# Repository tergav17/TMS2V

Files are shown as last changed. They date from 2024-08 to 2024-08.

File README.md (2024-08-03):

# TMS2V
This project aims to allow a V9938 VDP to be installed in place of a TMS9918A. Since the V9938 is (largely) backwards compatible with the TMS9918A, existing software for upgraded systems should still function as normal. 
Besides interposing the 40-pin socket that the TMS9918A plugged into, an extra address line may be attacked to the bus to allow for addressing of the addition 2 ports found on the V9938.

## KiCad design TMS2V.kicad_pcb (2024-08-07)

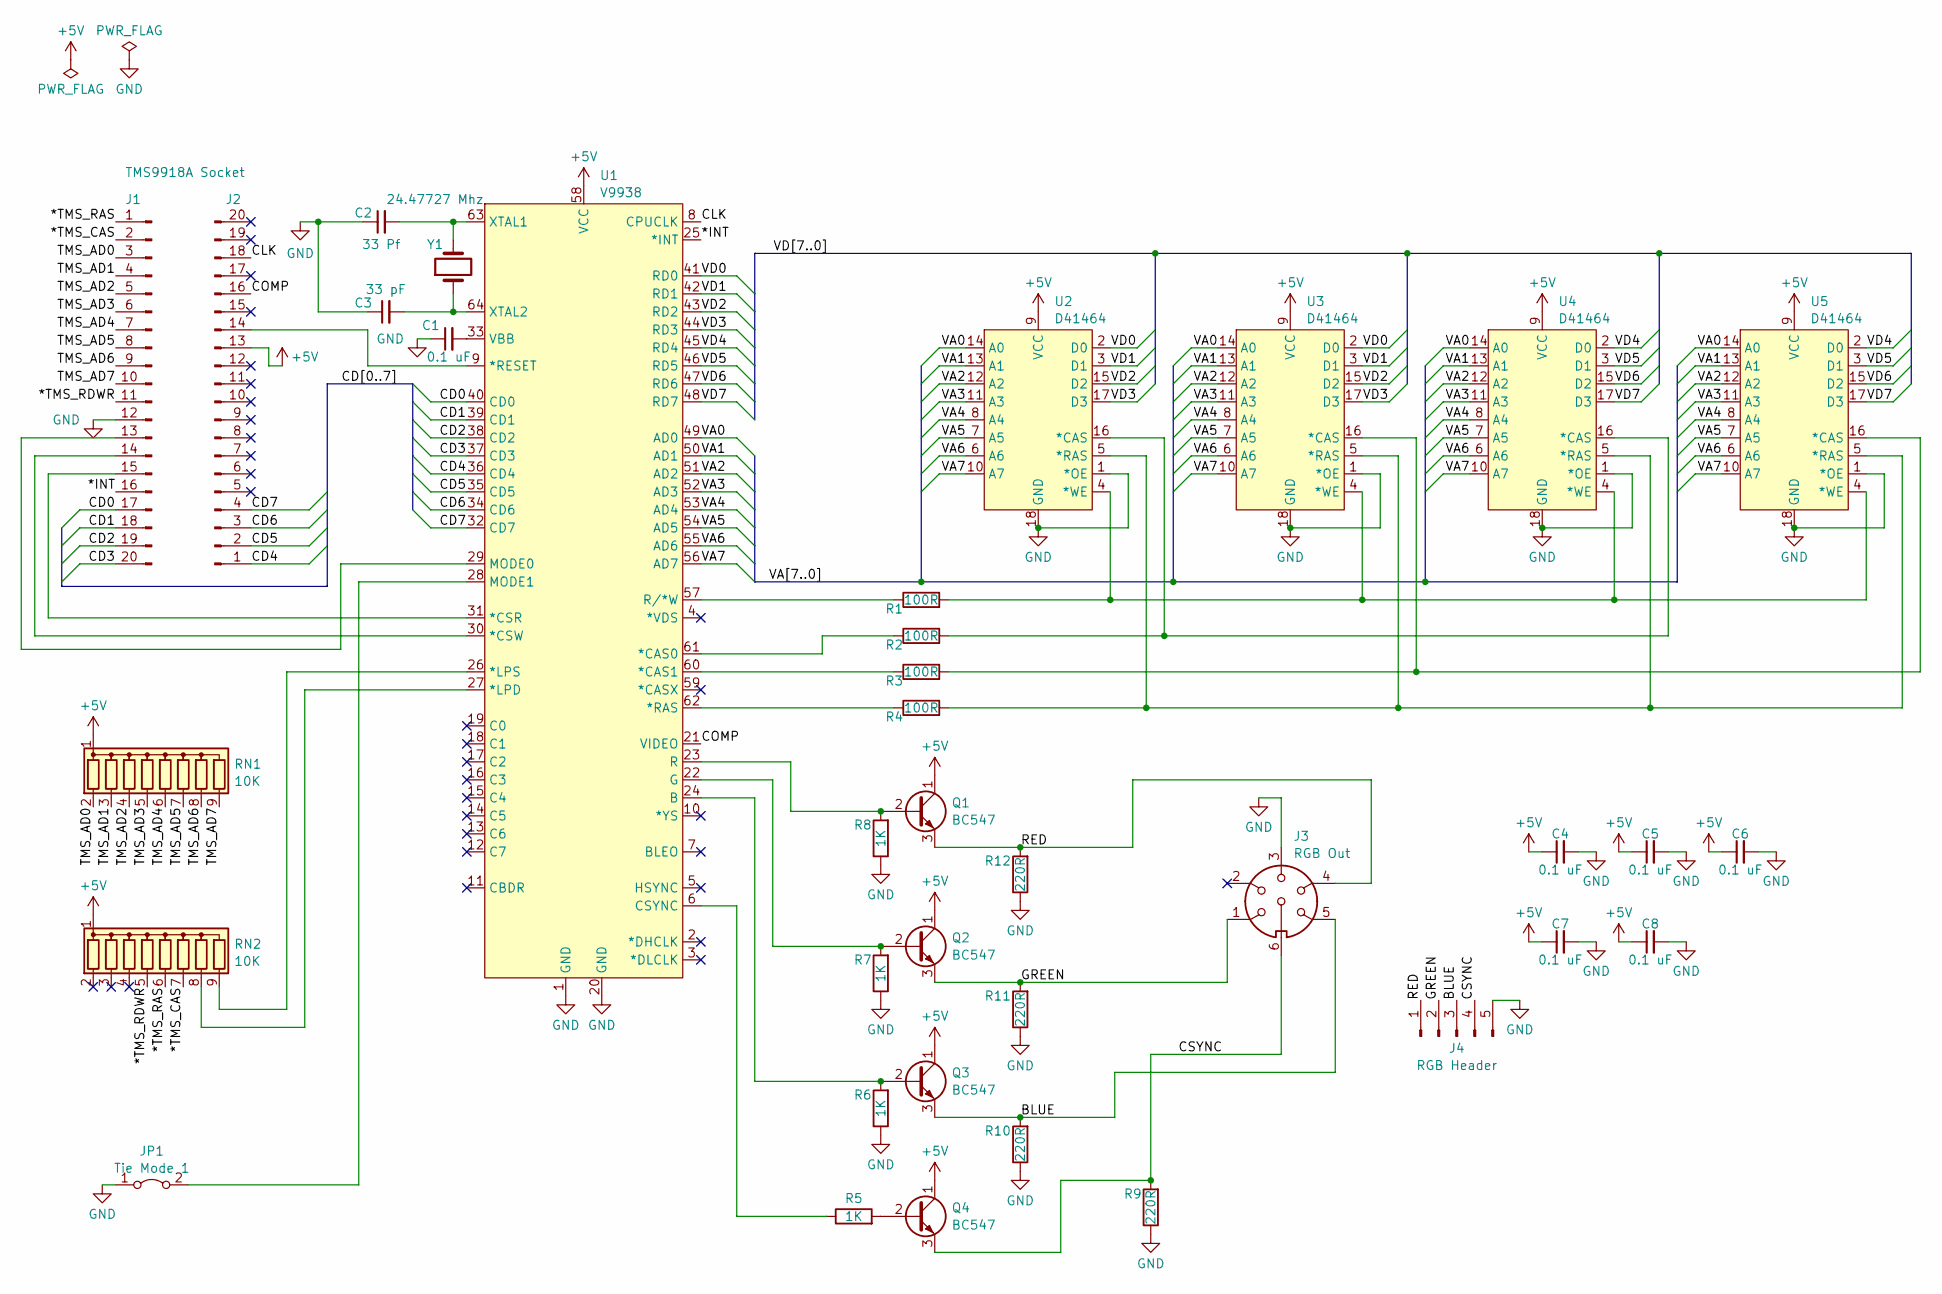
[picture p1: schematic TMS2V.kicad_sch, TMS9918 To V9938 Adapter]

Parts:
C1, C4, C5, C6, C7, C8: 0.1 uF; C_Disc_D5.0mm_W2.5mm_P5.00mm
C2: 33 Pf; C_Disc_D5.0mm_W2.5mm_P5.00mm
C3: 33 pF; C_Disc_D5.0mm_W2.5mm_P5.00mm
J1: TMS9918A Socket; PinHeader_1x20_P2.54mm_Vertical
J2: PinHeader_1x20_P2.54mm_Vertical
J3: RGB Out; DIN-6
J4: RGB Header; PinHeader_1x05_P2.54mm_Vertical
JP1: Tie Mode 1; PinHeader_1x02_P2.54mm_Vertical
Q1, Q2, Q3, Q4: BC547; TO-92_Inline
R1, R2, R3, R4: 100R; R_Axial_DIN0207_L6.3mm_D2.5mm_P7.62mm_Horizontal
R5, R6, R7, R8: 1K; R_Axial_DIN0207_L6.3mm_D2.5mm_P7.62mm_Horizontal
R9, R10, R11, R12: 220R; R_Axial_DIN0207_L6.3mm_D2.5mm_P7.62mm_Horizontal
RN1, RN2: 10K; R_Array_SIP9
U1: V9938; DIP64
U2, U3, U4, U5: D41464; DIP-18_W7.62mm
Y1: 24.47727 Mhz; Crystal_HC49-U_Vertical

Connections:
+5V: C4.1, C5.1, C6.1, C7.1, C8.1, J2.13, Q1.1 (C), Q2.1 (C), Q3.1 (C), Q4.1 (C), RN1.1 (common), RN2.1 (common), U1.58 (VCC), U2.9 (VCC), U3.9 (VCC), U4.9 (VCC), U5.9 (VCC)
/*INT: J1.16, U1.25 (*INT)
/*TMS_CAS: J1.2, RN2.7 (R6)
/*TMS_RAS: J1.1, RN2.6 (R5)
/*TMS_RDWR: J1.11, RN2.5 (R4)
/BLUE: J3.5, J4.3, Q3.3 (E), R10.2
/CD0: J1.17, U1.40 (CD0)
/CD1: J1.18, U1.39 (CD1)
/CD2: J1.19, U1.38 (CD2)
/CD3: J1.20, U1.37 (CD3)
/CD4: J2.1, U1.36 (CD4)
/CD5: J2.2, U1.35 (CD5)
/CD6: J2.3, U1.34 (CD6)
/CD7: J2.4, U1.32 (CD7)
/CLK: J2.18, U1.8 (CPUCLK)
/COMP: J2.16, U1.21 (VIDEO)
/CSYNC: J3.6, J4.4, Q4.3 (E), R9.2
/GREEN: J3.1, J4.2, Q2.3 (E), R11.2
/RED: J3.4, J4.1, Q1.3 (E), R12.2
/TMS_AD0: J1.3, RN1.2 (R1)
/TMS_AD1: J1.4, RN1.3 (R2)
/TMS_AD2: J1.5, RN1.4 (R3)
/TMS_AD3: J1.6, RN1.5 (R4)
/TMS_AD4: J1.7, RN1.6 (R5)
/TMS_AD5: J1.8, RN1.7 (R6)
/TMS_AD6: J1.9, RN1.8 (R7)
/TMS_AD7: J1.10, RN1.9 (R8)
/VA0: U1.49 (AD0), U2.14 (A0), U3.14 (A0), U4.14 (A0), U5.14 (A0)
/VA1: U1.50 (AD1), U2.13 (A1), U3.13 (A1), U4.13 (A1), U5.13 (A1)
/VA2: U1.51 (AD2), U2.12 (A2), U3.12 (A2), U4.12 (A2), U5.12 (A2)
/VA3: U1.52 (AD3), U2.11 (A3), U3.11 (A3), U4.11 (A3), U5.11 (A3)
/VA4: U1.53 (AD4), U2.8 (A4), U3.8 (A4), U4.8 (A4), U5.8 (A4)
/VA5: U1.54 (AD5), U2.7 (A5), U3.7 (A5), U4.7 (A5), U5.7 (A5)
/VA6: U1.55 (AD6), U2.6 (A6), U3.6 (A6), U4.6 (A6), U5.6 (A6)
/VA7: U1.56 (AD7), U2.10 (A7), U3.10 (A7), U4.10 (A7), U5.10 (A7)
/VD0: U1.41 (RD0), U2.2 (D0), U3.2 (D0)
/VD1: U1.42 (RD1), U2.3 (D1), U3.3 (D1)
/VD2: U1.43 (RD2), U2.15 (D2), U3.15 (D2)
/VD3: U1.44 (RD3), U2.17 (D3), U3.17 (D3)
/VD4: U1.45 (RD4), U4.2 (D0), U5.2 (D0)
/VD5: U1.46 (RD5), U4.3 (D1), U5.3 (D1)
/VD6: U1.47 (RD6), U4.15 (D2), U5.15 (D2)
/VD7: U1.48 (RD7), U4.17 (D3), U5.17 (D3)
GND: C1.1, C2.1, C3.1, C4.2, C5.2, C6.2, C7.2, C8.2, J1.12, J3.3, J4.5, JP1.1 (A), R6.1, R7.1, R8.1, R9.1, R10.1, R11.1, R12.1, U1.1 (GND), U1.20 (GND), U2.1 (*OE), U2.18 (GND), U3.1 (*OE), U3.18 (GND), U4.1 (*OE), U4.18 (GND), U5.1 (*OE), U5.18 (GND)
unnamed: J1.13, U1.29 (MODE0)
unnamed: J1.14, U1.30 (*CSW)
unnamed: J1.15, U1.31 (*CSR)
unnamed: J2.14, U1.9 (*RESET)
unnamed: JP1.2 (B), U1.28 (MODE1)
unnamed: Q1.2 (B), R8.2, U1.23 (R)
unnamed: Q2.2 (B), R7.2, U1.22 (G)
unnamed: Q3.2 (B), R6.2, U1.24 (B)
unnamed: Q4.2 (B), R5.2
unnamed: RN2.8 (R7), U1.27 (*LPD)
unnamed: RN2.9 (R8), U1.26 (*LPS)
unnamed: R2.1, U1.61 (*CAS0)
unnamed: R3.1, U1.60 (*CAS1)
unnamed: R4.1, U1.62 (*RAS)
unnamed: R5.1, U1.6 (CSYNC)
unnamed: R1.1, U1.57 (R/*W)
unnamed: C1.2, U1.33 (VBB)
unnamed: C2.2, U1.63 (XTAL1), Y1.2
unnamed: C3.2, U1.64 (XTAL2), Y1.1
unnamed: R2.2, U2.16 (*CAS), U4.16 (*CAS)
unnamed: R4.2, U2.5 (*RAS), U3.5 (*RAS), U4.5 (*RAS), U5.5 (*RAS)
unnamed: R1.2, U2.4 (*WE), U3.4 (*WE), U4.4 (*WE), U5.4 (*WE)
unnamed: R3.2, U3.16 (*CAS), U5.16 (*CAS)

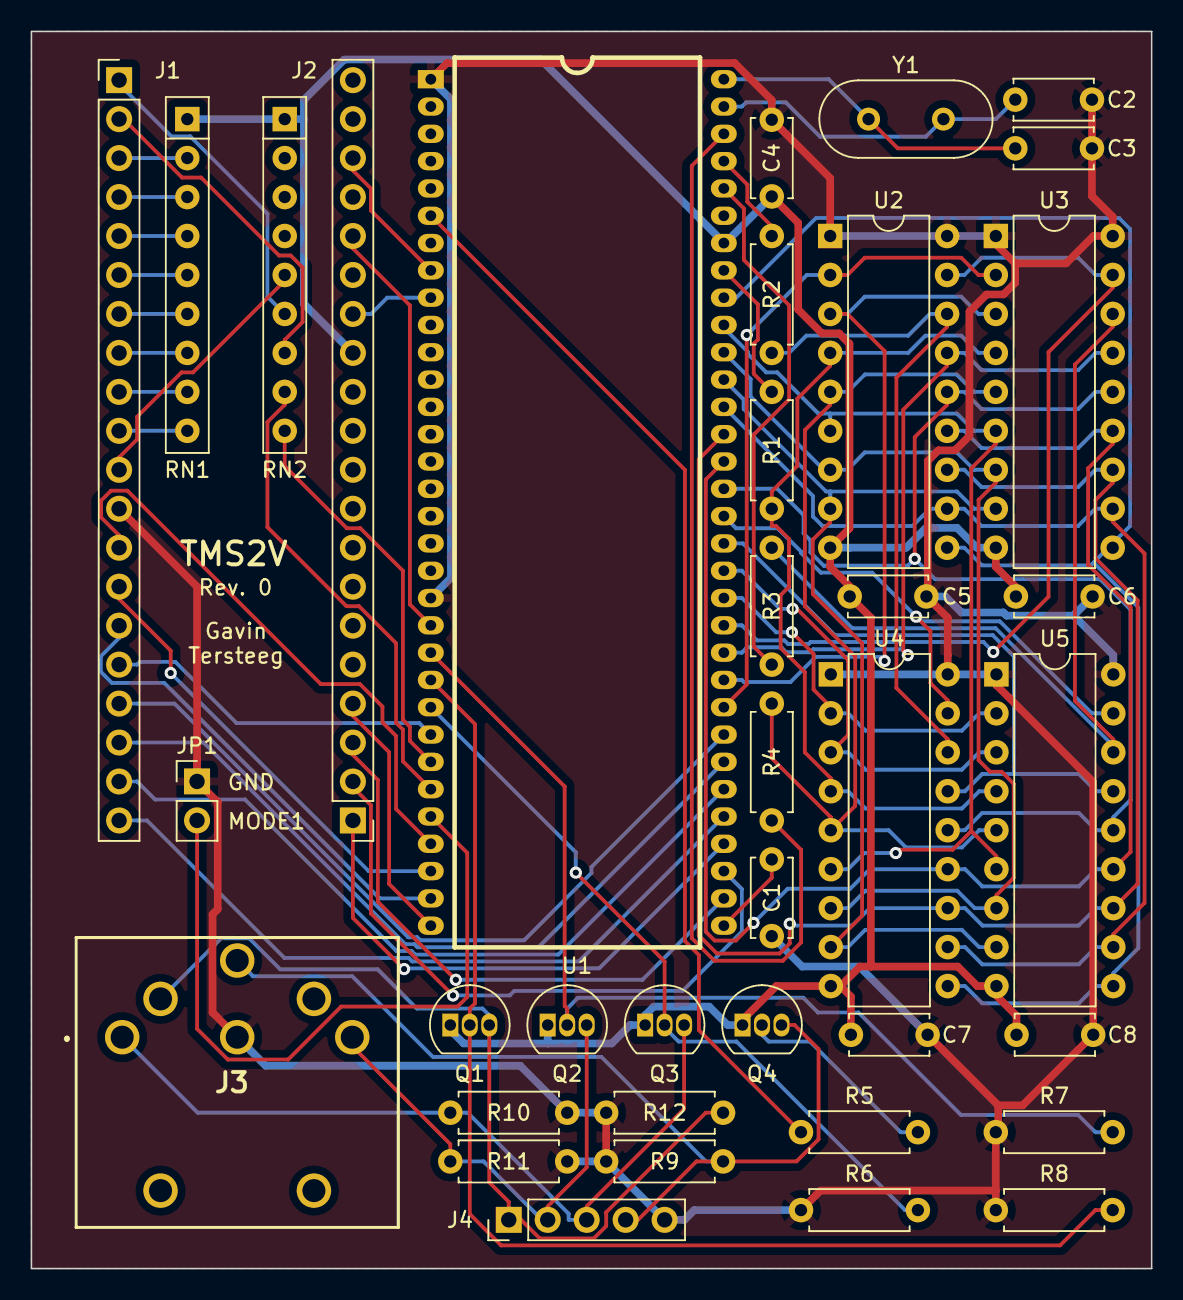
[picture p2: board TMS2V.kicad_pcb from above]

Board: 2 copper layers, 73.0 x 80.6 mm, 37 parts (0 on the bottom side), 67 nets.

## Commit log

2024-08-01 Added D41464 footprint and logic
    [TMS2V.kicad_sch]
2024-08-02 TMS9918A hookup
    [TMS2V.kicad_sch]
2024-08-04 oscillator circuit
    [TMS2V.kicad_sch]
2024-08-05 Started work on video output circuit
    [TMS2V.kicad_sch]
2024-08-06 Started work on PCB layout
    [TMS2V.kicad_pcb, TMS2V.kicad_sch]
2024-08-07 Initial PCB layout
    [TMS2V.kicad_pcb]
2024-08-07 Generated gerbers
    [TMS2V-B_Cu.gbr, TMS2V-B_Mask.gbr, TMS2V-B_Paste.gbr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]
